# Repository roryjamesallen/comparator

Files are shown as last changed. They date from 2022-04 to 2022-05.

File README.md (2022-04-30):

# comparator
#### A simple dual comparator in Eurorack format.
  
Inputs between +12V and -12V can be compared, and an output of 0 or 5V will be produced accordingly, indicated by the LED.
  
The voltage to compare input A against is controlled by the knob, and is be default 0-12V. However, this voltage can be replaced by plugging a jack into input B, in which case the knob will attenuate this input.

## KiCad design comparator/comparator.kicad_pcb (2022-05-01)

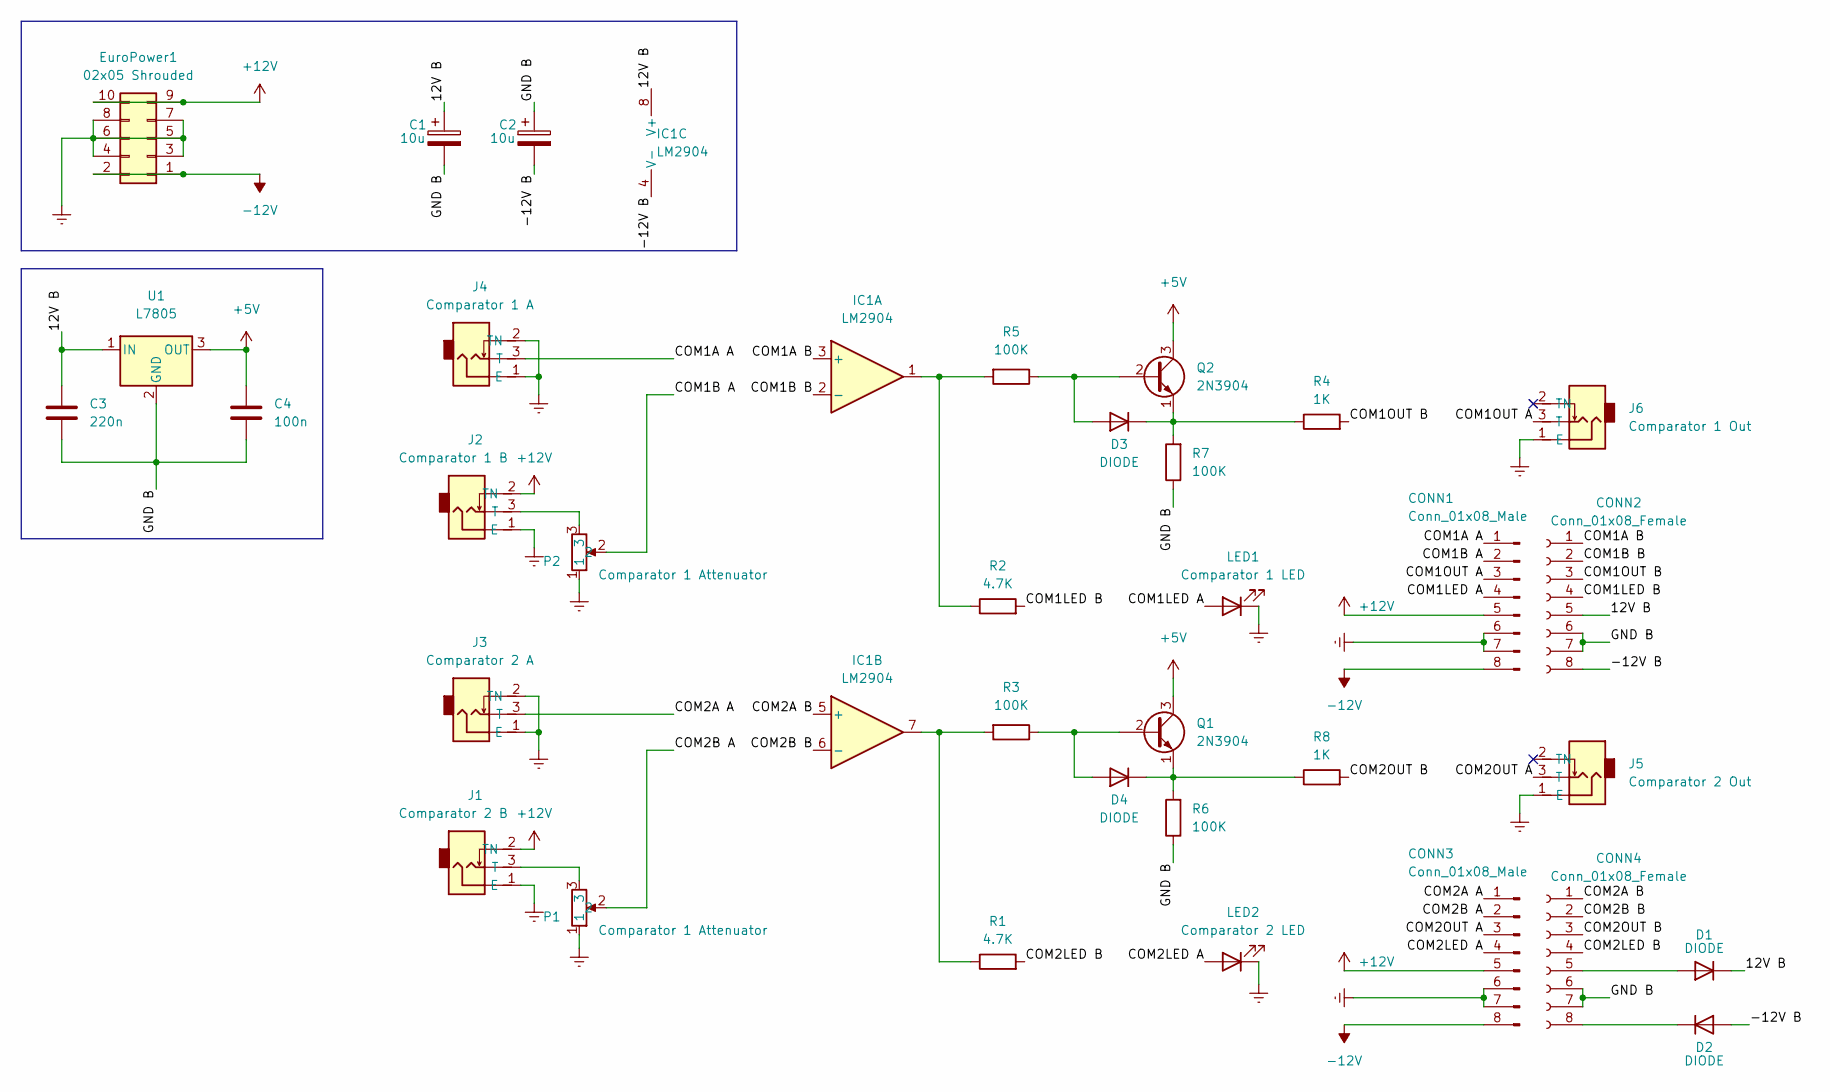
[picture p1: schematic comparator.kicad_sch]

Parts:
C1, C2: 10u; CP_Radial_D5.0mm_P2.50mm
C3: 220n; Capacitor Small Non-Polarised
C4: 100n; Capacitor Small Non-Polarised
CONN1, CONN3: Conn_01x08_Male; PinHeader_2x04_P2.54mm_Vertical
CONN2, CONN4: Conn_01x08_Female; PinSocket_2x04_P2.54mm_Vertical
D1, D2: DIODE; D_A-405_P7.62mm_Horizontal
D3, D4: DIODE; Schottky Diode
EuroPower1: 02x05 Shrouded; Eurorack Power Header Unlabeled
IC1: LM2904; DIP-8 IC Socket
J1: Comparator 2 B; Thonkiconn Mono Jack
J2: Comparator 1 B; Thonkiconn Mono Jack
J3: Comparator 2 A; Thonkiconn Mono Jack
J4: Comparator 1 A; Thonkiconn Mono Jack
J5: Comparator 2 Out; Thonkiconn Mono Jack
J6: Comparator 1 Out; Thonkiconn Mono Jack
LED1: Comparator 1 LED; LED 3mm
LED2: Comparator 2 LED; LED 3mm
P1, P2: Comparator 1 Attenuator; Potentiometer 9mm Vertical Linear
Q1, Q2: 2N3904; TO-92_Inline
R1, R2: 4.7K; Resistor 0.25W Through-Hole Short
R3, R5, R6, R7: 100K; Resistor 0.25W Through-Hole Short
R4, R8: 1K; Resistor 0.25W Through-Hole Short
U1: L7805; TO-92

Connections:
+5V: C4.1, Q1.3 (C), Q2.3 (C), U1.3 (OUT)
+12V: CONN1.5, CONN3.5, EuroPower1.9, EuroPower1.10, J1.2 (TN), J2.2 (TN)
-12V: CONN1.8, CONN3.8, EuroPower1.1, EuroPower1.2
/12V B: C1.1, C3.1, CONN2.5, D1.2 (K), IC1.8 (V+), U1.1 (IN)
/-12V B: C2.2, CONN2.8, D2.1 (A), IC1.4 (V-)
/COM1A A: CONN1.1, J4.3 (T)
/COM1A B: CONN2.1, IC1.3 (+)
/COM1B A: CONN1.2, P2.2
/COM1B B: CONN2.2, IC1.2 (-)
/COM1LED A: CONN1.4, LED1.2 (A)
/COM1LED B: CONN2.4, R2.2
/COM1OUT A: CONN1.3, J6.3 (T)
/COM1OUT B: CONN2.3, R4.2
/COM2A A: CONN3.1, J3.3 (T)
/COM2A B: CONN4.1, IC1.5 (+)
/COM2B A: CONN3.2, P1.2
/COM2B B: CONN4.2, IC1.6 (-)
/COM2LED A: CONN3.4, LED2.2 (A)
/COM2LED B: CONN4.4, R1.2
/COM2OUT A: CONN3.3, J5.3 (T)
/COM2OUT B: CONN4.3, R8.2
/GND B: C1.2, C2.1, C3.2, C4.2, CONN2.6, CONN2.7, CONN4.6, CONN4.7, R6.1, R7.1, U1.2 (GND)
Earth: CONN1.6, CONN1.7, CONN3.6, CONN3.7, EuroPower1.3, EuroPower1.4, EuroPower1.5, EuroPower1.6, EuroPower1.7, EuroPower1.8, J1.1 (E), J2.1 (E), J3.1 (E), J3.2 (TN), J4.1 (E), J4.2 (TN), J5.1 (E), J6.1 (E), LED1.1 (K), LED2.1 (K), P1.1, P2.1
unnamed: CONN4.5, D1.1 (A)
unnamed: CONN4.8, D2.2 (K)
unnamed: D3.1 (A), Q2.2 (B), R5.1
unnamed: D3.2 (K), Q2.1 (E), R4.1, R7.2
unnamed: D4.1 (A), Q1.2 (B), R3.1
unnamed: D4.2 (K), Q1.1 (E), R6.2, R8.1
unnamed: IC1.1, R2.1, R5.2
unnamed: IC1.7, R1.1, R3.2
unnamed: J1.3 (T), P1.3
unnamed: J2.3 (T), P2.3

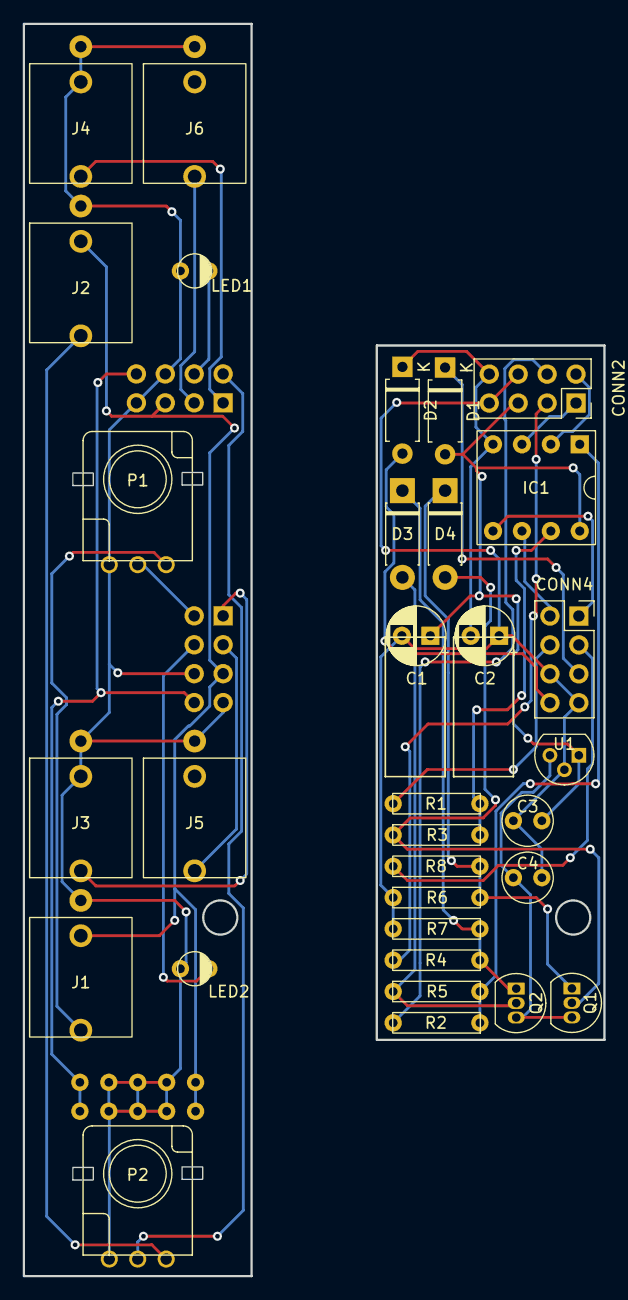
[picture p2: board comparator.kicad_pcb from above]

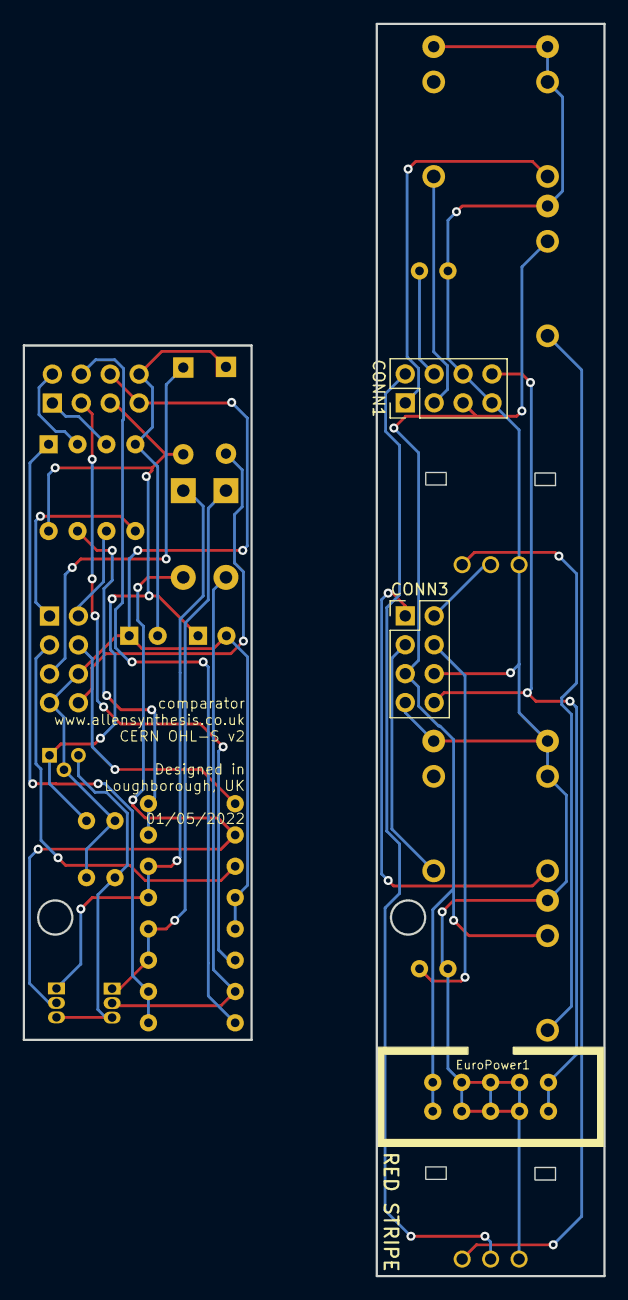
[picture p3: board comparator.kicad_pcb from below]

Board: 2 copper layers, 51.0 x 110.0 mm, 35 parts (3 on the bottom side), 33 nets.

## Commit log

2022-04-30 Create KiCad files
    [comparator.kicad_pcb, comparator.kicad_sch]
2022-05-01 KiCad changes
    [comparator.kicad_pcb, comparator.kicad_sch]

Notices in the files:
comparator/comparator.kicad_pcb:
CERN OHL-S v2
